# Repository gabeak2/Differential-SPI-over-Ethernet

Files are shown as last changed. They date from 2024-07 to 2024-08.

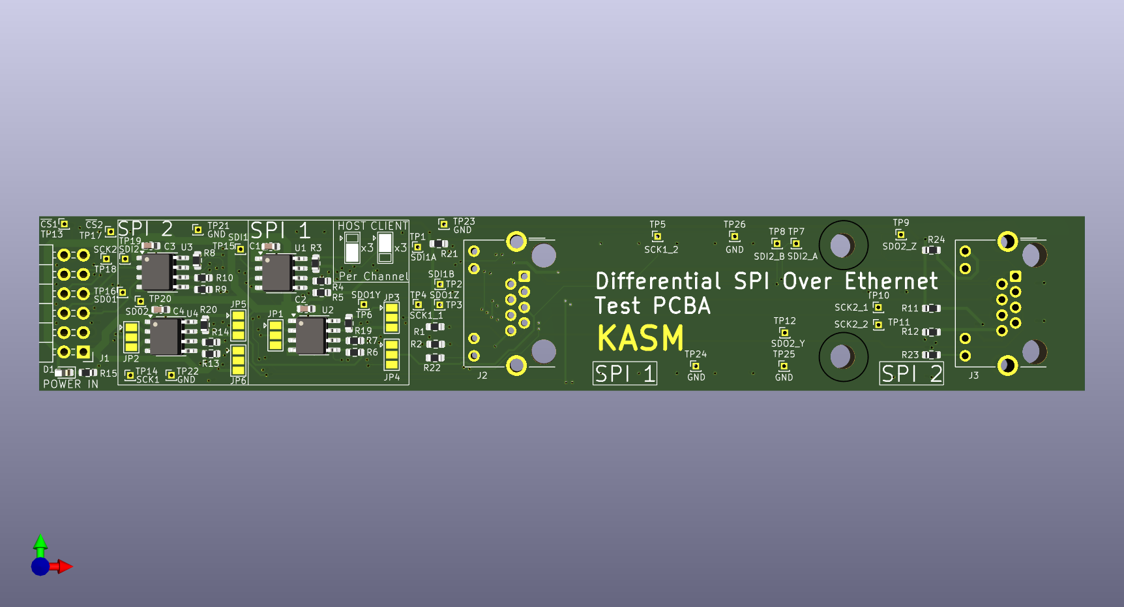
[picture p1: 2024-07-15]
3d_render_PMOD_differential_driver.png

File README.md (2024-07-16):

# Differential-SPI-over-Ethernet
The board is meant to drive 2 SPI channels differentially over ethernet cables, and plugs into those "PMOD" connectors that all the FPGA dev boards have (but they are just 6x2 R/A 100mil headers, so also compatible with dupont/breadboard wires).  Right now I have one SPI channel with 500kHz slew-rate-limited transceivers stuffed, and one with 15MHz ones, but the chips have an identical SOIC-8 footprint so it's just a BOM change to swap them around whichever way you like.  There are solder jumpers on the board that let you hook the transceivers up so that it works for either the host side or the client side (clk is an output on a SPI host, but an input on an SPI client board).  You can also try a UART-based communication system on this board by only hooking up some of the pins - it's worth mentioning that many modern MCUs can do "UART" at over 10MHz, so theoretically if this link is just between an FPGA and one of those MCUs there are no restrictions to conventional UART baud rates, and UART would use 1/2 the pins of SPI.  Although I do love how SPI seems just made to work over RJ45 and ethernet cables!

3d_render_PMOD_differential_driver

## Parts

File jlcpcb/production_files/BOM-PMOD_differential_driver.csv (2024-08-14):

Comment | Designator | Footprint | LCSC
100nF | C1,C2,C3,C4 | C_0603_1608Metric | C14663
0 | R1,R11,R12,R2 | R_0603_1608Metric | C21189
1k | R15,R21,R22,R23,R24 | R_0603_1608Metric | C21190
110 | R19,R20,R3,R8 | R_0603_1608Metric | C22781
620 | R10,R13,R14,R4,R5,R6,R7,R9 | R_0603_1608Metric | C23220
R/A 100mil Header 6x2 | J1 | pmod_mating_conn | C60565
Yellow | D1 | LED_0603_1608Metric | C72038
RJ45_LED | J2,J3 | RJ45_Connfly_DS1128-09-S8xx-S_Horizontal | C86578
SP3078EEN | U1,U2,U3,U4 | SOIC-8_3.9x4.9mm_P1.27mm | C95362
TestPoint | TP19 | PinHeader_1x01_P1.00mm_Vertical
TestPoint | TP13 | PinHeader_1x01_P1.00mm_Vertical
TestPoint | TP15 | PinHeader_1x01_P1.00mm_Vertical
TestPoint | TP10 | PinHeader_1x01_P1.00mm_Vertical
TestPoint | TP26 | PinHeader_1x01_P1.00mm_Vertical
TestPoint | TP17 | PinHeader_1x01_P1.00mm_Vertical
TestPoint | TP25 | PinHeader_1x01_P1.00mm_Vertical
TestPoint | TP1 | PinHeader_1x01_P1.00mm_Vertical
TestPoint | TP4 | PinHeader_1x01_P1.00mm_Vertical
TestPoint | TP3 | PinHeader_1x01_P1.00mm_Vertical
TestPoint | TP18 | PinHeader_1x01_P1.00mm_Vertical
TestPoint | TP24 | PinHeader_1x01_P1.00mm_Vertical
TestPoint | TP5 | PinHeader_1x01_P1.00mm_Vertical
TestPoint | TP12 | PinHeader_1x01_P1.00mm_Vertical
TestPoint | TP9 | PinHeader_1x01_P1.00mm_Vertical
TestPoint | TP2 | PinHeader_1x01_P1.00mm_Vertical
TestPoint | TP21 | PinHeader_1x01_P1.00mm_Vertical
TestPoint | TP7 | PinHeader_1x01_P1.00mm_Vertical
TestPoint | TP14 | PinHeader_1x01_P1.00mm_Vertical
TestPoint | TP6 | PinHeader_1x01_P1.00mm_Vertical
TestPoint | TP23 | PinHeader_1x01_P1.00mm_Vertical
TestPoint | TP8 | PinHeader_1x01_P1.00mm_Vertical
TestPoint | TP16 | PinHeader_1x01_P1.00mm_Vertical
TestPoint | TP22 | PinHeader_1x01_P1.00mm_Vertical
TestPoint | TP20 | PinHeader_1x01_P1.00mm_Vertical
TestPoint | TP11 | PinHeader_1x01_P1.00mm_Vertical

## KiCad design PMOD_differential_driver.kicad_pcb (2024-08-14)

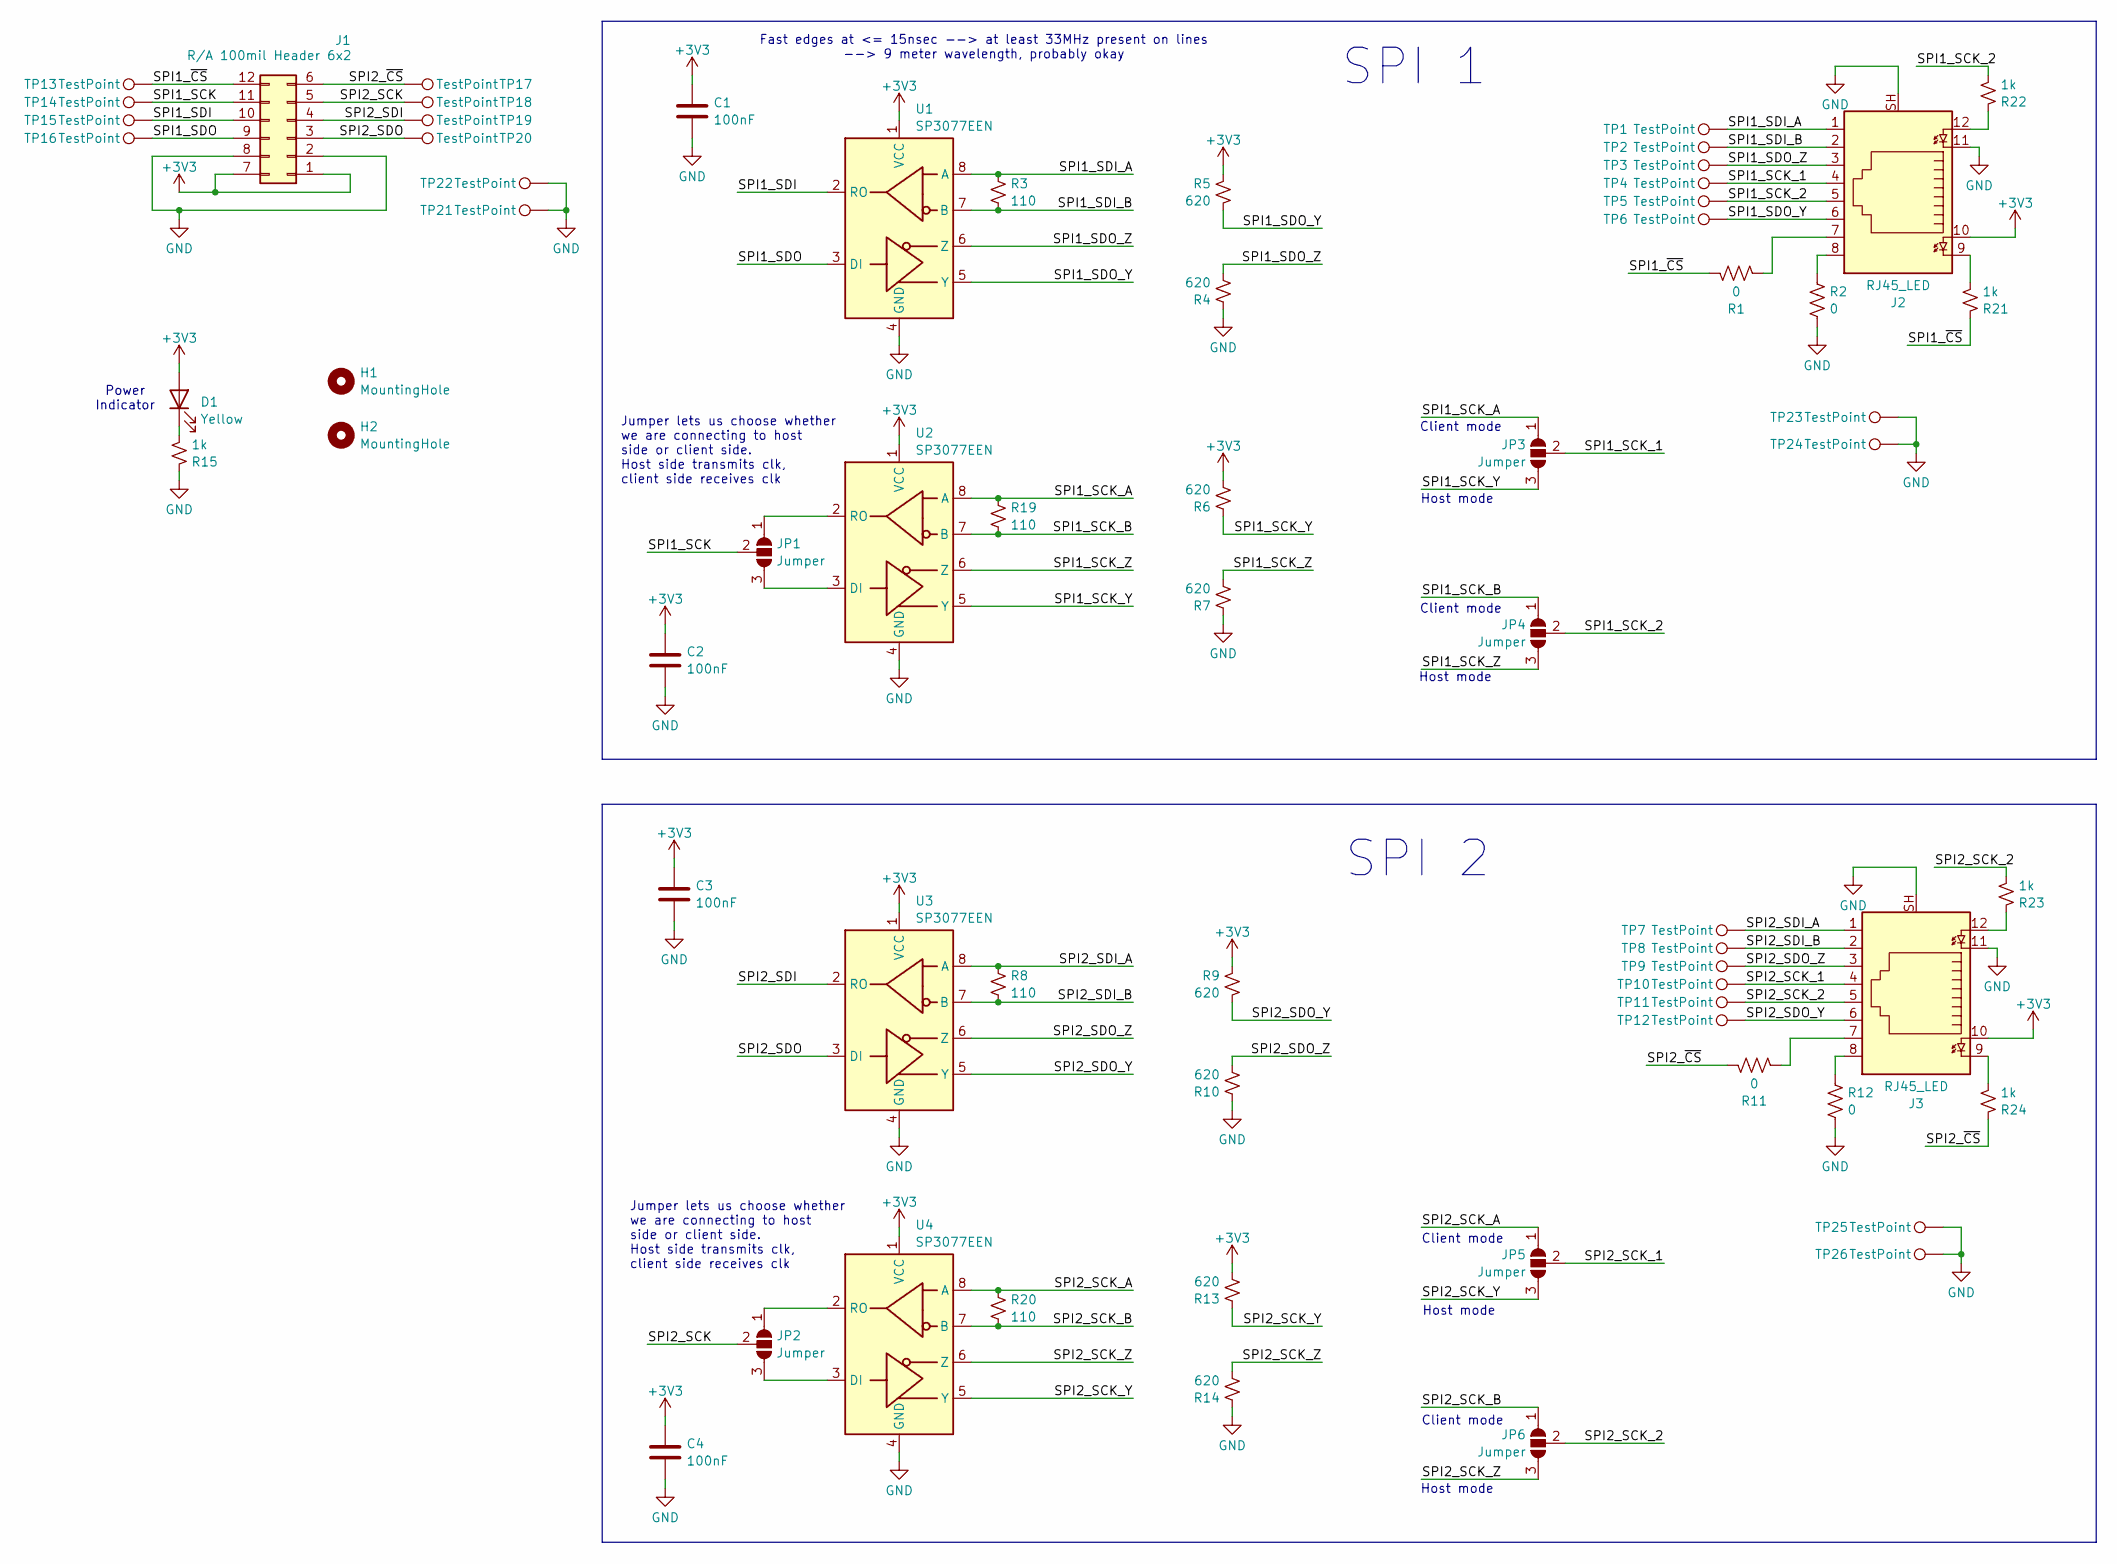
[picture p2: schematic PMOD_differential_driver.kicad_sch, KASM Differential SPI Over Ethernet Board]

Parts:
C1, C2, C3, C4: 100nF; C_0603_1608Metric; LCSC C14663
D1: Yellow; LED_0603_1608Metric; LCSC C72038
H1, H2: MountingHole; MountingHole_3.2mm_M3
J1: R/A 100mil Header 6x2; pmod_mating_conn; LCSC C60565
J2, J3: RJ45_LED; RJ45_Connfly_DS1128-09-S8xx-S_Horizontal; LCSC C86578
JP1, JP2, JP3, JP4, JP5, JP6: Jumper; SolderJumper-3_P1.3mm_Open_Pad1.0x1.5mm
R1, R2, R11, R12: 0; R_0603_1608Metric; LCSC C21189
R3, R8, R19, R20: 110; R_0603_1608Metric; LCSC C22781
R4, R5, R6, R7, R9, R10, R13, R14: 620; R_0603_1608Metric; LCSC C23220
R15, R21, R22, R23, R24: 1k; R_0603_1608Metric; LCSC C21190
TP1, TP2, TP3, TP4, TP5, TP6, TP7, TP8, TP9, TP10, TP11, TP12, TP13, TP14, TP15, TP16, TP17, TP18, TP19, TP20, TP21, TP22, TP23, TP24, TP25, TP26: TestPoint; PinHeader_1x01_P1.00mm_Vertical
U1, U2, U3, U4: SP3077EEN; SOIC-8_3.9x4.9mm_P1.27mm; LCSC C916162

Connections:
+3V3: C1.1, C2.1, C3.1, C4.1, D1.2 (A), J1.1, J1.7, J2.10, J3.10, R5.2, R6.2, R9.2, R13.2, U1.1 (VCC), U2.1 (VCC), U3.1 (VCC), U4.1 (VCC)
/SPI1_SCK: J1.11, JP1.2 (C), TP14.1
/SPI1_SCK_1: J2.4, JP3.2 (C), TP4.1
/SPI1_SCK_2: J2.5, JP4.2 (C), R22.2, TP5.1
/SPI1_SCK_A: JP3.1 (A), R19.1, U2.8 (A)
/SPI1_SCK_B: JP4.1 (A), R19.2, U2.7 (B)
/SPI1_SCK_Y: JP3.3 (B), R6.1, U2.5 (Y)
/SPI1_SCK_Z: JP4.3 (B), R7.2, U2.6 (Z)
/SPI1_SDI: J1.10, TP15.1, U1.2 (RO)
/SPI1_SDI_A: J2.1, R3.1, TP1.1, U1.8 (A)
/SPI1_SDI_B: J2.2, R3.2, TP2.1, U1.7 (B)
/SPI1_SDO: J1.9, TP16.1, U1.3 (DI)
/SPI1_SDO_Y: J2.6, R5.1, TP6.1, U1.5 (Y)
/SPI1_SDO_Z: J2.3, R4.2, TP3.1, U1.6 (Z)
/SPI1_~CS: J1.12, R1.2, R21.1, TP13.1
/SPI2_SCK: J1.5, JP2.2 (C), TP18.1
/SPI2_SCK_1: J3.4, JP5.2 (C), TP10.1
/SPI2_SCK_2: J3.5, JP6.2 (C), R23.2, TP11.1
/SPI2_SCK_A: JP5.1 (A), R20.1, U4.8 (A)
/SPI2_SCK_B: JP6.1 (A), R20.2, U4.7 (B)
/SPI2_SCK_Y: JP5.3 (B), R13.1, U4.5 (Y)
/SPI2_SCK_Z: JP6.3 (B), R14.2, U4.6 (Z)
/SPI2_SDI: J1.4, TP19.1, U3.2 (RO)
/SPI2_SDI_A: J3.1, R8.1, TP7.1, U3.8 (A)
/SPI2_SDI_B: J3.2, R8.2, TP8.1, U3.7 (B)
/SPI2_SDO: J1.3, TP20.1, U3.3 (DI)
/SPI2_SDO_Y: J3.6, R9.1, TP12.1, U3.5 (Y)
/SPI2_SDO_Z: J3.3, R10.2, TP9.1, U3.6 (Z)
/SPI2_~CS: J1.6, R11.2, R24.1, TP17.1
GND: C1.2, C2.2, C3.2, C4.2, J1.2, J1.8, J2.11, J2.SH, J3.11, J3.SH, R2.1, R4.1, R7.1, R10.1, R12.1, R14.1, R15.1, TP21.1, TP22.1, TP23.1, TP24.1, TP25.1, TP26.1, U1.4 (GND), U2.4 (GND), U3.4 (GND), U4.4 (GND)
unnamed: D1.1 (K), R15.2
unnamed: J2.7, R1.1
unnamed: J2.8, R2.2
unnamed: J2.9, R21.2
unnamed: J2.12, R22.1
unnamed: J3.7, R11.1
unnamed: J3.8, R12.2
unnamed: J3.9, R24.2
unnamed: J3.12, R23.1
unnamed: JP1.1 (A), U2.2 (RO)
unnamed: JP1.3 (B), U2.3 (DI)
unnamed: JP2.1 (A), U4.2 (RO)
unnamed: JP2.3 (B), U4.3 (DI)

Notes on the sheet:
SPI 1
SPI 2
Client mode
Host mode
Fast edges at <= 15nsec --> at least 33MHz present on lines --> 9 meter wavelength, probably okay
Power Indicator
Jumper lets us choose whether we are connecting to host side or client side. Host side transmits clk, client side receives clk

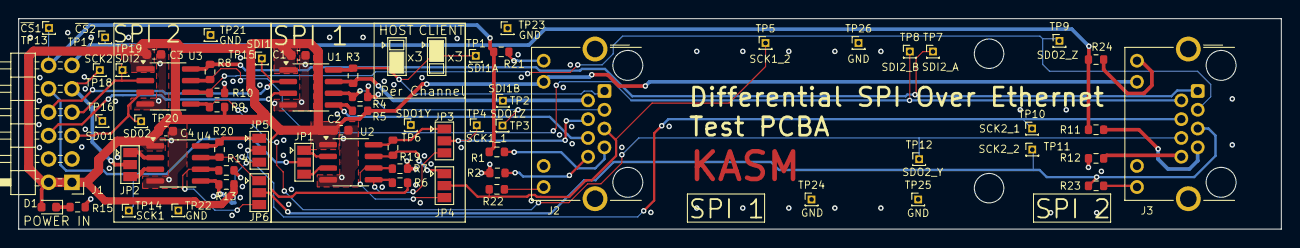
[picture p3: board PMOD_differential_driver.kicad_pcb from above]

Board: 4 copper layers, 137.2 x 22.9 mm, 67 parts (0 on the bottom side), 43 nets.
